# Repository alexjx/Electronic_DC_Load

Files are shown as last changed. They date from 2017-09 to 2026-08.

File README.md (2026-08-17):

# Electronic Controlled DC Dummy Load

An Arduino-compatible electronic load built around an ATmega328P. It draws a
controlled current from a DC source and displays the measured current, voltage,
power, temperature, and accumulated capacity.

> [!WARNING]
> This is an experimental high-power project, not a certified test instrument.
> The 15 A and 200 W values are firmware ceilings, not proven continuous hardware
> ratings. Safe operation depends on the input voltage, IRFP250N safe operating
> area, heatsink, airflow, shunt and PCB heating, wiring, connectors, calibration,
> and an external fuse. Begin with a current-limited supply at low power and do not
> leave the load unattended. The refactored firmware has not yet been validated on
> the physical hardware.

## Hardware overview

The load uses a power MOSFET as a variable resistance. A precision shunt measures
the resulting current, while the firmware adjusts a DAC until measured current
matches the requested value.

```text
Source under test -> J1 -> IRFP250N -> 5 mOhm shunt -> ground
                         ^                   |
                         |                   +-> INA213 -> AD7190 ADC
ATmega328P -> AD5541 DAC -> AD8629 gate-control amplifier
```

| Part | Purpose |
| --- | --- |
| ATmega328P-AU, 16 MHz | Runs the user interface, safety checks, and current controller |
| AD7190 | Measures load voltage and shunt current |
| AD5541 | Produces the analog current command |
| AD8629 | Buffers voltage sensing and drives the MOSFET control loop |
| INA213 and 5 mOhm / 4 W shunt | Measures load current |
| IRFP250N | Dissipates the power drawn from the source |
| LM35 | Measures heatsink temperature |
| 16x2 LCD and PCF8574 | Displays settings and measurements over I2C |
| REF5050 | Provides the 5 V ADC, DAC, and analog reference |

### Connections

| Connector | Function | Notes |
| --- | --- | --- |
| J1 | DC source under test | Schematic pad 2 is load positive; pad 1 is return/ground. Confirm this against the assembled PCB before applying power. |
| J2 | Control-power input | Feeds the MP1584 supply stage. The repository does not document a safe input-voltage range or jack polarity; verify the assembled board before use. |
| J3 | AVR ISP | Programming connector for the ATmega328P |
| J4 | Cooling fan | Nominal 12 V fan output controlled by the firmware |

The complete Eagle design is in [`schematic/`](schematic/). The design files
label the input-divider resistor as 9.9 kOhm, while the purchase record says the
fitted part is 9.09 kOhm. The firmware follows the purchase record; confirm the
assembled value and verify readings against calibrated meters before power testing.

## Controls and display

The top LCD row shows the current setpoint, cutoff voltage, and operating status.
A blank status means idle; `*` means the load is running. The LCD cursor identifies
the digit changed by the rotary encoder.

| Control | Action |
| --- | --- |
| Rotate encoder | Change the selected current or cutoff-voltage digit |
| S1 / D4 | Move the selected digit left |
| S4 / D6 | Move the selected digit right |
| S3 / D3 | Show the previous measurement page |
| S2 / D5 | Show the next measurement page |
| Hold encoder switch | Start loading after the controller has been idle for at least 3 seconds |
| Click encoder while running | Stop loading immediately |
| Click encoder on a cleared fault | Acknowledge the fault and return to idle |

The four bottom-row pages show:

1. Measured current and voltage.
2. Calculated power and heatsink temperature.
3. Session capacity in mAh.
4. Session energy in Wh.

The mAh and Wh counters reset whenever a new load session starts. The setpoints are
saved when a session starts or stops.

## Usage guide

1. With all power disconnected, inspect the board, fit an adequate heatsink and
   fan, and add a suitable external fuse to the source-under-test connection.
2. Confirm J1 polarity and the required J2 voltage and polarity from the actual
   assembled board. Connect the fan to J4, then apply control power to J2.
3. Check that the display starts normally and that no fault is reported. Verify the
   voltage, current, and temperature readings before enabling the power stage.
4. Use S1/S4 to select a digit and rotate the encoder to set the desired current and
   low-voltage cutoff. Start with a small current.
5. Turn the current-limited source off, connect it to J1 with the verified polarity,
   and then turn the source on.
6. After the controller has been idle for at least 3 seconds, hold the encoder switch
   until loading starts. Confirm that `*` appears and watch current, power, and
   temperature while testing.
7. Click the encoder to stop. Confirm that `*` disappears before disconnecting the
   source.

The firmware limits the setpoint to 15.000 A, reduces the current request above a
calculated 200 W, trips overcurrent at 16.5 A, and trips overtemperature at 95 degC.
These protections supplement rather than replace correctly rated hardware and an
external fuse.

### Faults

Any firmware fault commands the DAC to zero and latches the load off.

| Display | Meaning | Before acknowledging |
| --- | --- | --- |
| `FAULT ADC` | ADC did not initialize or respond in time | Check ADC power, SPI wiring, and ready signal |
| `FAULT TEMP SNS` | Temperature reading is outside the plausible sensor range | Check the LM35 and its wiring |
| `FAULT OVERCUR` | Measured current exceeded 16.5 A | Remove the cause of excess current |
| `FAULT UNDERVOLT` | Source voltage fell below the configured cutoff | Recharge, replace, or disconnect the source |
| `FAULT OVERTEMP` | Temperature exceeded 95 degC | Keep cooling active and wait for the load to cool |

After correcting the cause, click the encoder when the display says
`Click to ack`. Acknowledgement only returns the controller to idle; it does not
restart the load. A condition that is still unsafe will fault again or refuse to
clear.

## Firmware build and tests

Initialize the pinned libraries, then build the Arduino Uno firmware:

```sh
git submodule update --init --recursive
make -C code clean
make -C code
```

Run the hardware-independent safety and driver tests with:

```sh
make -C code/tests clean
make -C code/tests
```

See [`code/BUILDING.md`](code/BUILDING.md) for the tested Ubuntu/WSL environment,
tool versions, generated files, and current flashing limitations.

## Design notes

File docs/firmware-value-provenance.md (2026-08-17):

# Firmware Value Provenance

This document records where the firmware's electrical conversion constants and
protection limits came from. It separates values confirmed by the repository's
schematic and PCB from engineering policy values that still require physical
validation.

## Source priority

Values are resolved in this order:

1. The component actually fitted to the assembled board.
2. The [schematic](../schematic/Electronic%20DC%20Load.sch) and
   [PCB](../schematic/Electronic%20DC%20Load.brd).
3. Manufacturer datasheets for the confirmed fitted component.
4. Existing firmware behavior.
5. Conservative firmware policy where the hardware does not define a value.

The repository labels current-sense amplifier U3 as an INA210. The assembled
board is reported to use an **INA213**, so the firmware intentionally uses the
INA213 nominal gain of 50 V/V. This override should be confirmed from the
physical package marking or purchase record.

The schematic and PCB label input-divider resistor R5 as 9.9 kOhm. The purchase
record instead identifies the fitted value as **9.09 kOhm**. The firmware uses
the fitted value, giving a 10.09:1 divider with R11. A resistance measurement on
an unpowered board should confirm it when practical.

## Confirmed transfer values

| Quantity | Repository evidence | Firmware value | Confidence |
| --- | --- | ---: | --- |
| Analog reference | U1, REF5050 | 5.0 V | High |
| Current shunt | R1, `.005` | 5 mOhm | High |
| Current-sense gain | Fitted U3 reported as INA213 | 50 V/V | Medium until physically confirmed |
| Input-voltage divider | Purchase record: R5 = 9.09 kOhm; R11 = 1 kOhm | 10.09:1 | Medium until physically confirmed |
| DAC divider | R12 = 39 kOhm, R8 = 10 kOhm | 10/49 | High |
| ADC | U2, AD7190BRUZ | AD7190 | High |
| DAC | U6, AD5541ARZ | AD5541 | High |

The schematic and PCB agree on the reference, shunt, and DAC-divider values.
They disagree with the purchase record for input-divider R5. Net tracing
confirms that R5/R11 feed the voltage measurement path and R12/R8 feed the
AD8629 current-control loop.

The single source of truth for these nominal values is
[`code/control.h`](../code/control.h). The ADC adapter uses the same functions
for its uncalibrated safety readings, avoiding a second set of constants.

## Current measurement

For a 5 mOhm shunt and INA213 gain of 50 V/V:

```text
amplifier_output = load_current * 0.005 * 50
                 = load_current * 0.25

load_current = amplifier_output / 0.25
```

At 15 A, the nominal amplifier output is 3.75 V.

This equation is used for absolute current and power protection without applying
the historical calibration coefficients.

## Input-voltage measurement

The fitted R5 and R11 values form a 9.09 kOhm / 1 kOhm divider:

```text
divider_ratio = (9.09k + 1k) / 1k
              = 10.09

input_voltage = ADC_input * 10.09
```

At a 50 V input, the nominal ADC input is approximately 4.955 V. The theoretical
5 V measurement full scale corresponds to only 50.45 V at the load input. The
present 50 V firmware trip therefore has less than 1% nominal input-voltage
headroom. It should not be increased, and lowering it requires deciding the
intended maximum operating voltage. In either case, this calculation is **not**
proof that the complete load is safe to dissipate power near 50 V.

## DAC current command

The AD5541 output is divided by R12 and R8 before reaching the AD8629 current
servo. The servo compares that target with the voltage across the 5 mOhm shunt:

```text
DAC_voltage = DAC_code / 65536 * 5.0

target_shunt_voltage = DAC_voltage * 10k / (39k + 10k)

target_current = target_shunt_voltage / 0.005
```

The ideal DAC code for 15 A is:

```text
15 * 0.005 * (39k + 10k) / 10k * 65536 / 5
= 4816.896 codes
```

The current firmware rounds this to a 4,817-code hard ceiling, corresponding to
approximately 15.0003 A nominally. A strict mathematical safety floor would be
4,816 codes, corresponding to approximately 14.9972 A. Component tolerances are
much larger than this one-code difference, but flooring is the cleaner policy
when the limit must never exceed nominal 15 A.

## Calibration boundary

The existing ADC calibration coefficients have no documented provenance:

| AD7190 gain | Scale | Offset |
| --- | ---: | ---: |
| 1 | 1.00080 | 4.0 mV |
| 8 | 1.00243 | -0.60 mV |

They remain available for displayed measurements and session accounting. They
do not change the nominal current, voltage, power, or DAC safety ceilings.
Accurate display and energy results require these coefficients to be confirmed
with traceable bench measurements.

## Engineering policy values

The following values are not directly established by resistor ratios or a
validated system-level hardware rating:

| Policy | Current value | Basis and limitation | Confidence as a safe physical limit |
| --- | ---: | --- | --- |
| User current ceiling | 15 A | Historical firmware setting and nominal DAC model | Medium |
| Overcurrent trip | 16.5 A | 10% above the command ceiling; backup protection | Medium |
| Input-voltage trip | 50 V | Only 0.45 V nominal source-side ADC headroom with the fitted divider | Low |
| Measured-power trip | 200 W | Retained historical firmware value | Low |
| Continuous command limit | 180 W | 10% margin below the historical value | Low |
| Thermal derating start | 80 C | Conservative firmware policy | Low |
| Thermal trip | 95 C | Historical firmware value | Low |
| Upward current slew | 5 A/s | Firmware transient-limiting policy | Medium |
| No-source threshold | 0.1 V | Noise/compliance guard | Medium |
| Cutoff qualification | 500 ms, 0.1 V hysteresis | Noise-rejection policy | Medium |
| AD7190 conversion timeout | 100 ms | Expected conversion time plus margin | Medium |
| I2C transaction timeout | 1 ms | Expected 100 kHz bus transaction plus margin | Medium |

In particular, 180 W or 200 W must not be interpreted as a validated continuous
rating. The safe load envelope depends on the IRFP250N DC safe-operating-area
curve, drain voltage, heatsink thermal resistance, airflow, ambient temperature,
sensor placement, gate-loop stability, wiring, and protection response time.

## Required physical verification

Before relying on the limits for real power testing:

1. Confirm that U3 on the assembled board is an INA213.
2. Confirm the fitted shunt and divider values, especially the R5 discrepancy,
   including tolerances.
3. Measure the REF5050 voltage and the current-to-DAC transfer at low power.
4. Verify ADC current and voltage readings against traceable instruments.
5. Establish a conservative voltage/current/time envelope from the fitted
   IRFP250N datasheet and actual cooling system.
6. Measure startup, current-step, source-disconnect, fault, and stop transients
   with an oscilloscope.
7. Validate heatsink, fan, and LM35 behavior at controlled increasing power.
8. Confirm that the ADC and I2C timeout margins are reliable on the assembled
   hardware.

Until these checks are complete, the firmware limits should be treated as
defensive bounds derived from the available design information, not as a
certified operating envelope.

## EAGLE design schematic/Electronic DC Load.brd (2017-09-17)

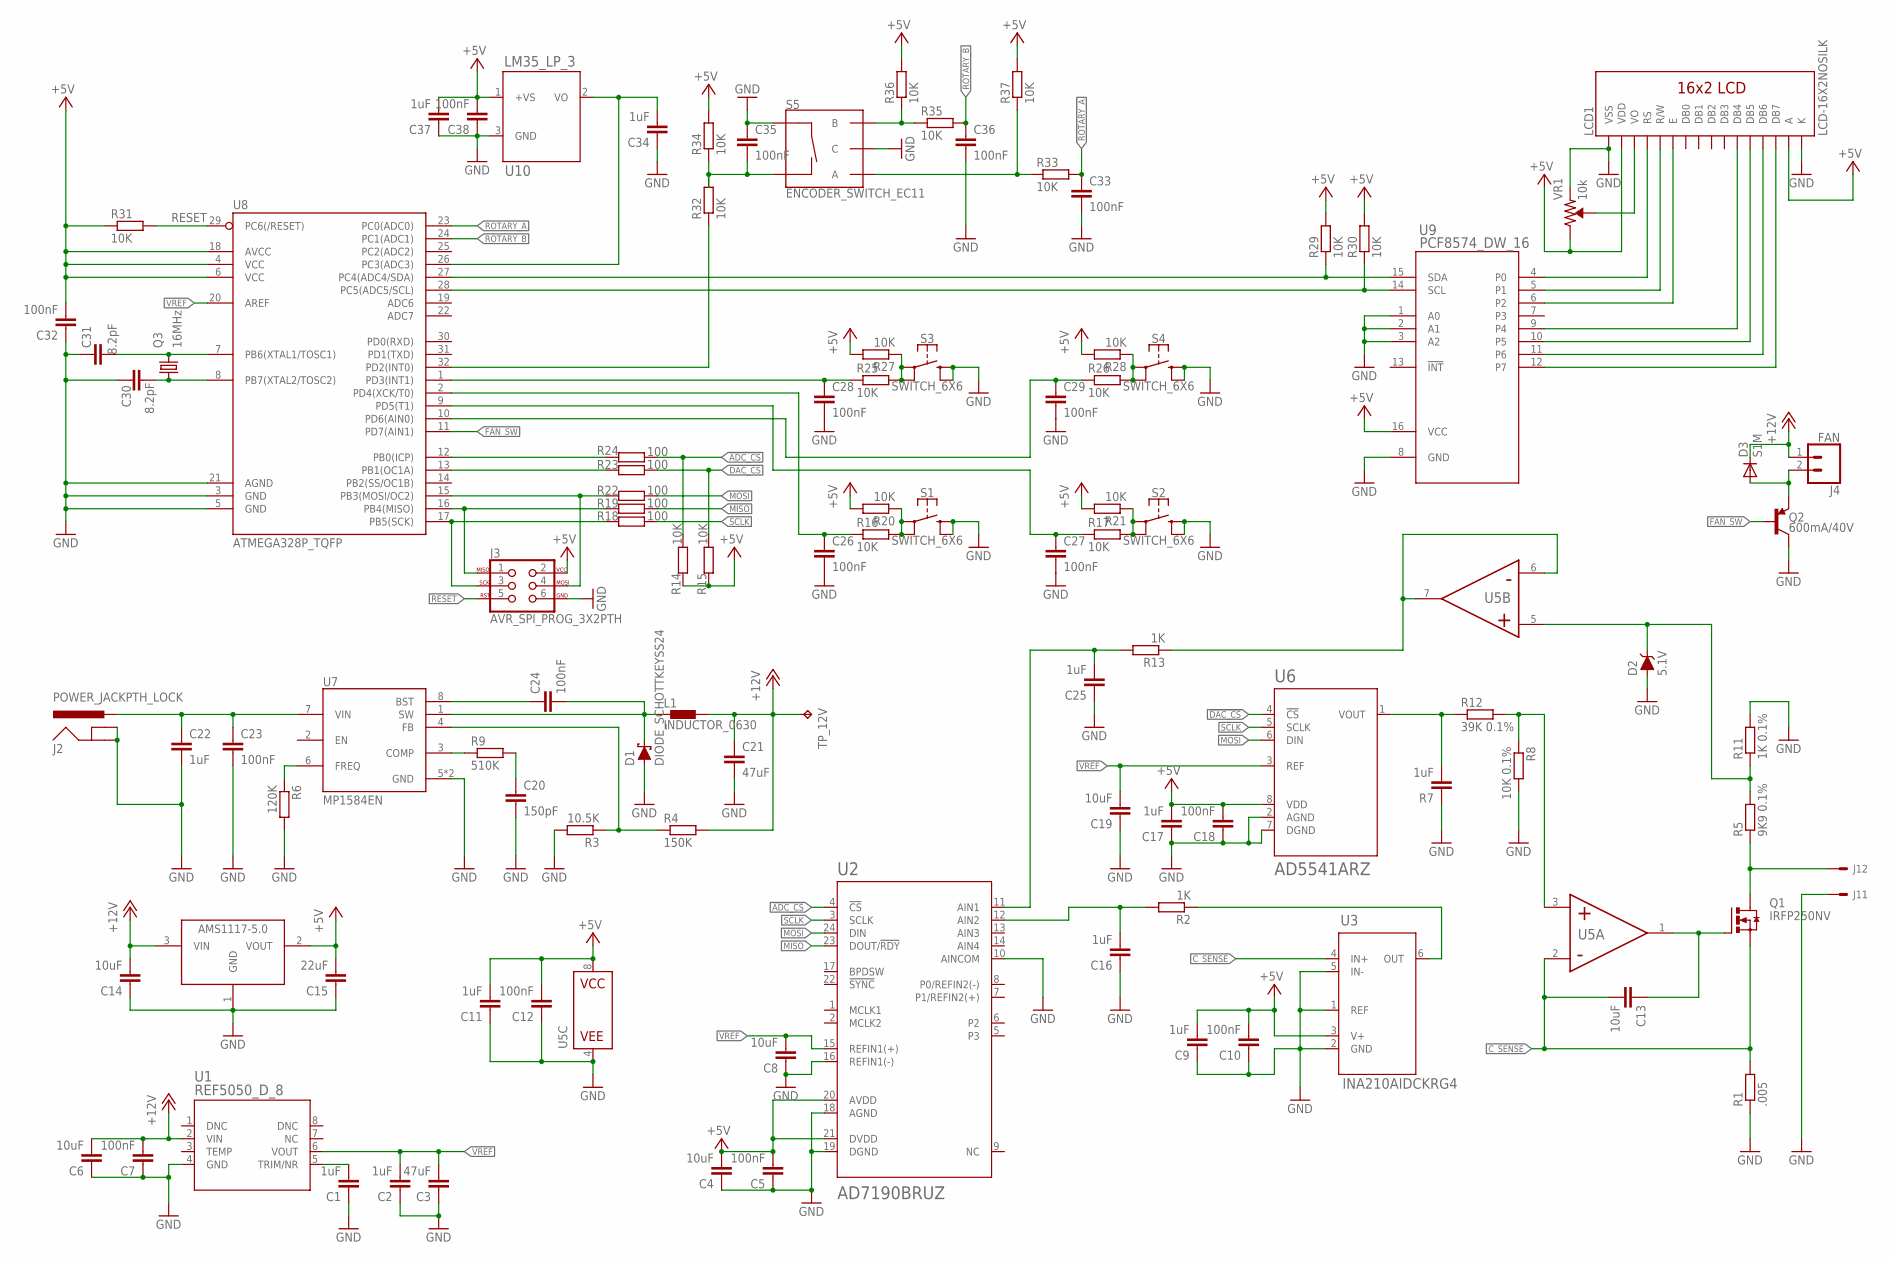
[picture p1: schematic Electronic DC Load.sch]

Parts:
C1, C2, C9, C11, C16, C17, C22, C25, C34, C37: 1uF; C0805
C3, C21: 47uF; C1206
C4, C6, C8, C13, C14, C19: 10uF; C1206
C5, C7, C10, C12, C18, C23, C24, C38: 100nF; C0805
C15: 22uF; C1206
C20: 150pF; C0402
C26, C27, C28, C29, C32, C33, C35, C36: 100nF; C0603
C30, C31: 8.2pF; C0603
D1: DIODE_SCHOTTKEYSS24; SMA-DIODE
D2: 5.1V; LL-34
D3: S1M; SMA
J1: KF762-2
J2: POWER_JACKPTH_LOCK; POWER_JACK_PTH_LOCK
J3: AVR_SPI_PROG_3X2PTH; 2X3
J4: FAN; 1X02_LOCK_LONGPADS
L1: INDUCTOR_0630
LCD1: LCD-16X2NOSILK; LCD-16X2_NOSILK
Q1: IRFP250NV; TO247BV
Q2: 600mA/40V; SOT23-3
Q3: 16MHz; 3.2X2.5_KX-7
R1: .005; 2728
R2, R13: 1K; R0805
R3: 10.5K; R0603
R4: 150K; R0603
R5: 9K9 0.1%; M0805
R6: 120K; R0603
R7: 1uF; C0805
R8: 10K 0.1%; R0805
R9: 510K; R0603
R11: 1K 0.1%; M0805
R12: 39K 0.1%; R0805
R14, R15: 10K; M0805
R16, R17, R20, R21, R25, R26, R27, R28, R29, R30, R31, R32, R33, R34, R35, R36, R37: 10K; R0603
R18, R19, R22, R23, R24: 100; M0805
S1, S2, S3, S4: SWITCH_6X6; SWITCH_SMD_6MM
S5: ENCODER_SWITCH_EC11; ROTARY_ENCODER_EC11
TP_12V: TPB1,27; B1,27
U1: REF5050_D_8; D8
U2: AD7190BRUZ; RU_24
U3: INA210AIDCKRG4; DCK0006A_N
U4: AMS1117-5.0; SOT223
U5: AD8629ARZ; R_8
U6: AD5541ARZ; R_8
U7: MP1584EN; SOIC9P127_490X600X170L84X42T330X241N
U8: ATMEGA328P_TQFP; TQFP32-08
U9: PCF8574_DW_16; DW16
U10: LM35_LP_3; Z03A
VR1: 10k; TRIMPOT-SMD-TC33X

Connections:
!ADC_CS: R14.2, R24.2, U2.4 (!CS)
!DAC_CS: R15.2, R23.2, U6.4 (!CS)
+5V: C4.2, C5.2, C9.2, C10.2, C11.2, C12.2, C15.2, C17.2, C18.2, C32.2, C37.2, C38.2, J3.2, LCD1.2 (VDD), LCD1.15 (A), R14.1, R15.1, R20.2, R21.2, R27.2, R28.2, R29.2, R30.2, R31.1, R34.2, R36.2, R37.2, U2.20 (AVDD), U2.21 (DVDD), U3.3 (V+), U4.2 (VOUT), U5.8 (VCC), U6.8 (VDD), U8.4 (VCC), U8.6 (VCC), U8.18 (AVCC), U9.16 (VCC), U10.1 (+VS), VR1.1 (CW)
+12V: C6.2, C7.2, C14.2, C21.1, D3.C, J4.1, L1.P$2 (2), R4.2, TP_12V.TP, U1.2 (VIN), U4.3 (VIN)
C_SENSE: C13.2, Q1.S, R1.2, U3.4 (IN+), U5.2 (IN-)
FAN_SW: Q2.1 (B), U8.11 (PD7(AIN1))
GND: C1.1, C2.1, C3.1, C4.1, C5.1, C6.1, C7.1, C8.1, C9.1, C10.1, C11.1, C12.1, C14.1, C15.1, C16.1, C17.1, C18.1, C19.1, C20.2, C21.2, C22.2, C23.2, C25.1, C26.2, C27.2, C28.2, C29.2, C30.1, C31.1, C32.1, C33.2, C34.1, C35.1, C36.2, C37.1, C38.1, D1.A, D2.A, J1.1, J2.GND, J2.GNDBREAK, J3.6, LCD1.1 (VSS), LCD1.16 (K), Q2.3 (C), R1.1, R3.2, R6.2, R7.1, R8.2, R11.2, S1.B1 (3), S1.B2 (4), S2.B1 (3), S2.B2 (4), S3.B1 (3), S3.B2 (4), S4.B1 (3), S4.B2 (4), S5.C, S5.D (SW+), U1.4 (GND), U2.10 (AINCOM), U2.16 (REFIN1(-)), U2.18 (AGND), U2.19 (DGND), U3.1 (REF), U3.2 (GND), U3.5 (IN-), U4.1 (GND), U5.4 (VEE), U6.2 (AGND), U6.7 (DGND), U7.5 (GND), U7.9 (GND), U8.3 (GND), U8.5 (GND), U8.21 (AGND), U9.1 (A0), U9.2 (A1), U9.3 (A2), U9.8 (GND), U10.3 (GND), VR1.3 (CCW)
MISO: R19.2, U2.23 (DOUT/!RDY)
MOSI: R22.2, U2.24 (DIN), U6.6 (DIN)
unnamed: R29.1, U8.27 (PC4(ADC4/SDA)), U9.15 (SDA)
unnamed: R30.1, U8.28 (PC5(ADC5/SCL)), U9.14 (SCL)
unnamed: LCD1.11 (DB4), U9.9 (P4)
unnamed: LCD1.12 (DB5), U9.10 (P5)
unnamed: LCD1.13 (DB6), U9.11 (P6)
unnamed: LCD1.14 (DB7), U9.12 (P7)
unnamed: LCD1.4 (RS), U9.4 (P0)
unnamed: LCD1.5 (R/W), U9.5 (P1)
unnamed: LCD1.6 (E), U9.6 (P2)
unnamed: C1.2, U1.5 (TRIM/NR)
unnamed: C31.2, Q3.3 (2), U8.7 (PB6(XTAL1/TOSC1))
unnamed: C30.2, Q3.1, U8.8 (PB7(XTAL2/TOSC2))
unnamed: LCD1.3 (VO), VR1.2 (WIPER)
unnamed: J1.2, Q1.D, R5.1
unnamed: C34.2, U8.26 (PC3(ADC3)), U10.2 (VO)
unnamed: C25.2, R13.2, U2.11 (AIN1)
unnamed: R6.1, U7.6 (FREQ)
unnamed: R2.1, U3.6 (OUT)
unnamed: C24.1, U7.8 (BST)
unnamed: C22.1, C23.1, J2.PWR, U7.7 (VIN)
unnamed: C24.2, D1.C, L1.P$1 (1), U7.1 (SW)
unnamed: R3.1, R4.1, U7.4 (FB)
unnamed: R9.1, U7.3 (COMP)
unnamed: C16.2, R2.2, U2.12 (AIN2)
unnamed: C20.1, R9.2
unnamed: R7.2, R12.1, U6.1 (VOUT)
unnamed: R13.1, U5.6 (IN-), U5.7 (OUT)
unnamed: D3.A, J4.2, Q2.2 (E)
unnamed: R35.1, R36.1, S5.B
unnamed: J3.3, R18.1, U8.17 (PB5(SCK))
unnamed: J3.1, R19.1, U8.16 (PB4(MISO))
unnamed: J3.4, R22.1, U8.15 (PB3(MOSI/OC2))
unnamed: R23.1, U8.13 (PB1(OC1A))
unnamed: R24.1, U8.12 (PB0(ICP))
unnamed: C13.1, Q1.G, U5.1 (OUT)
unnamed: D2.C, R5.2, R11.1, U5.5 (IN+)
unnamed: R33.1, R37.1, S5.A
unnamed: R8.1, R12.2, U5.3 (IN+)
unnamed: R16.2, R20.1, S1.A1 (1), S1.A2 (2)
unnamed: R25.2, R27.1, S3.A1 (1), S3.A2 (2)
unnamed: C35.2, R32.2, R34.1, S5.E (SW-)
unnamed: C26.1, R16.1, U8.2 (PD4(XCK/T0))
unnamed: R32.1, U8.32 (PD2(INT0))
unnamed: C28.1, R25.1, U8.1 (PD3(INT1))
unnamed: R26.2, R28.1, S4.A1 (1), S4.A2 (2)
unnamed: R17.2, R21.1, S2.A1 (1), S2.A2 (2)
unnamed: C27.1, R17.1, U8.9 (PD5(T1))
unnamed: C29.1, R26.1, U8.10 (PD6(AIN0))
RESET: J3.5, R31.2, U8.29 (PC6(/RESET))
ROTARY_A: C33.1, R33.2, U8.23 (PC0(ADC0))
ROTARY_B: C36.1, R35.2, U8.24 (PC1(ADC1))
SCLK: R18.2, U2.3 (SCLK), U6.5 (SCLK)
VREF: C2.2, C3.2, C8.2, C19.2, U1.6 (VOUT), U2.15 (REFIN1(+)), U6.3 (REF), U8.20 (AREF)

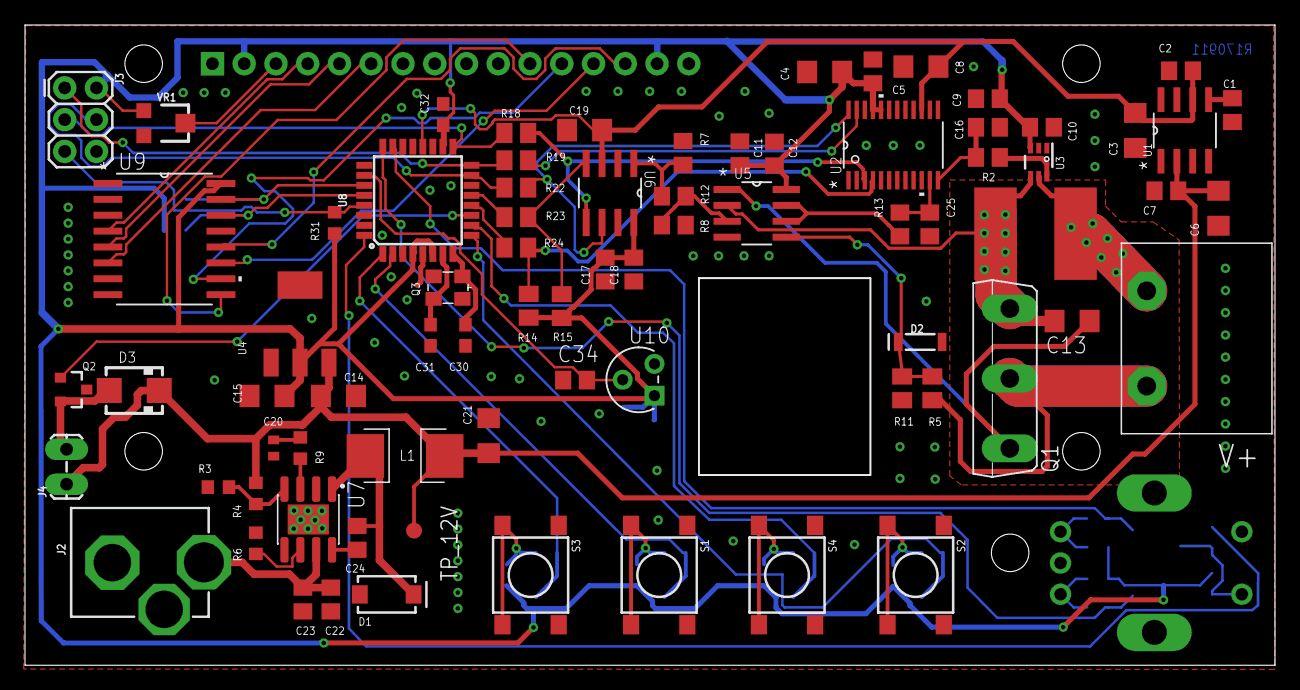
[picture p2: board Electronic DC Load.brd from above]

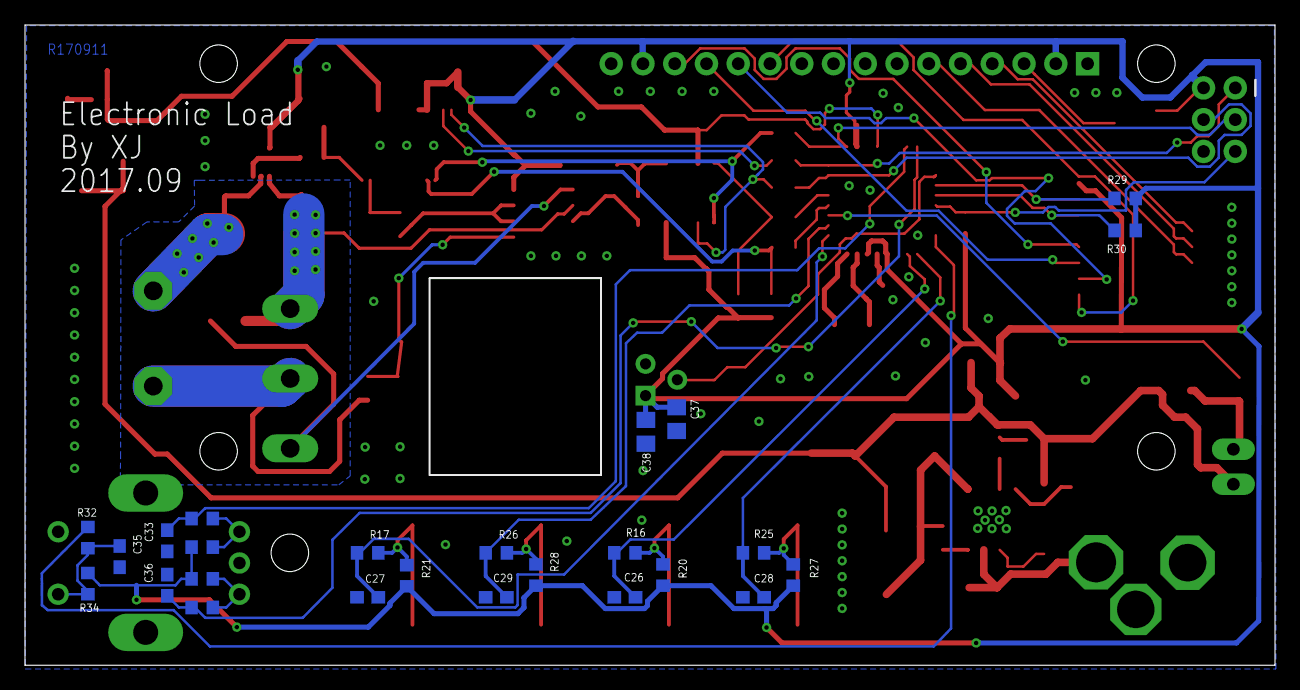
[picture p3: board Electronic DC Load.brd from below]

Board: 2 copper layers, 100.0 x 51.2 mm, 103 parts (25 on the bottom side), 62 nets.

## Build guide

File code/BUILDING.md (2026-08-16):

# Building the firmware in WSL

The firmware targets an Arduino Uno-compatible ATmega328P running at 16 MHz.

## One-time setup

On Ubuntu 22.04 under WSL:

```sh
sudo apt-get update
sudo apt-get install -y arduino-core-avr arduino-mk gcc-avr avr-libc avrdude make g++
git submodule update --init --recursive
```

The repository pins the external Arduino libraries through Git submodules. The
Ubuntu packages provide the AVR compiler, Arduino AVR core, and Arduino-Makefile.

Versions used to reproduce the baseline build:

- Arduino AVR core: `1.8.4+dfsg1-1`
- Arduino-Makefile: `1.5.2-2.1`
- avr-gcc/avr-g++: `5.4.0`
- avr-libc: `2.0.0`
- GNU Make: `4.3`

## Build

From the repository root:

```sh
make -C code clean
make -C code
```

Build artifacts are written under `code/bin/` and ignored by Git. The `.hex`
file is the image used for flashing.

## Host safety tests

Run the hardware-independent controller and driver tests with:

```sh
make -C code/tests clean
make -C code/tests
```

The tests use strict compiler warnings plus AddressSanitizer and
UndefinedBehaviorSanitizer. Test binaries are written to
`/tmp/electronic_dc_load_tests`, not the repository.

The Makefile defaults to the Ubuntu package location, `/usr/share/arduino`.
`ARDMK_DIR` and `ARDUINO_DIR` can still be overridden on the command line for a
different installation.

## WSL hardware note

Compiling does not require USB access. Uploading from WSL additionally requires
the Arduino's USB serial device to be attached to WSL and may require adjusting
`MONITOR_PORT`; flashing has not yet been verified on physical hardware.

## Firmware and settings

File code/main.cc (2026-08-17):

#include <Arduino.h>
#include <Wire.h>
#include <SPI.h>
#include <TimerOne.h>
#include <LiquidCrystal_I2C.h>
#include <ClickEncoder.h>
#include <EEPROM.h>

#include "ad5541.h"
#include "adc.h"
#include "button.h"
#include "fan.h"
#include "setter.h"
#include "lm35.h"
#include "control.h"


// Hardware Configuration
#define LCD_IIC_ADDRESS      0x20
#define LCD_IIC_COLS         16
#define LCD_IIC_ROWS         2

#define ENCODER_PIN_1        A0
#define ENCODER_PIN_2        A1
#define ENCODER_SW_PIN       2
#define ENCODER_UPDATE_RATE  4


#define ADC_CS_PIN           8
#define DAC_CS_PIN           9

#define BUTTON_1_PIN         3
#define BUTTON_2_PIN         4
#define BUTTON_3_PIN         6
#define BUTTON_4_PIN         5

#define FAN_SW_PIN           7
#define LM35_PIN             A3

#define MAX_BUTTON           4

#define ADC_CURRENT_CHN      AD7190_CH_AIN2P_AINCOM
#define ADC_VOLTAGE_CHN      AD7190_CH_AIN1P_AINCOM

#define EEPROM_VERSION_ADDR  0x00
#define EEPROM_VERSION       0x0a

#define EEPROM_CURRENT_ADDR  0x10
#define EEPROM_VOLTAGE_ADDR  0x20


// Constants
const double VREF_VOLTAGE = 5000.0;  // mV

const double MAX_WATTAGE = 200.0;
const double CONTINUOUS_WATTAGE = 180.0;
const double MAX_INPUT_VOLTAGE = 50.0;
const double MIN_SOURCE_VOLTAGE = 0.1;

constexpr int32_t MAX_CURRENT_MILLIAMPS = 15000;
constexpr double MAX_CURRENT = MAX_CURRENT_MILLIAMPS / 1000.0;

const double MAX_TEMPERATURE = 95.0;
const double THERMAL_DERATE_START = 80.0;

const int MAX_PAGE = 4;
const uint32_t DISPLAY_UPDATE_INTERVAL_MS = 200UL;
const uint32_t WIRE_TIMEOUT_US = 1000UL;


///////////////////////
// Devices
///////////////////////

// DAC
AD5541 ad5541(DAC_CS_PIN);


// ADC
ADConverter adc(ADC_CS_PIN,
                ADC_VOLTAGE_CHN,
                ADC_CURRENT_CHN,
                VREF_VOLTAGE);


// LCD
LiquidCrystal_I2C lcd(LCD_IIC_ADDRESS,
                      LCD_IIC_COLS,
                      LCD_IIC_ROWS);


// encoder
ClickEncoder encoder(ENCODER_PIN_1,
                     ENCODER_PIN_2,
                     ENCODER_SW_PIN,
                     ENCODER_UPDATE_RATE);


// Buttons
Button buttons[MAX_BUTTON] {
    BUTTON_1_PIN,
    BUTTON_2_PIN,
    BUTTON_3_PIN,
    BUTTON_4_PIN,
};


// FAN
FanController fan(FAN_SW_PIN);


// temperature sensor
LM35 lm35(LM35_PIN, VREF_VOLTAGE);


// Setter (max 15000mA)
Setter<MAX_CURRENT_MILLIAMPS> current_set_point;
// Cut off voltage set
Setter<99999l> voltage_set_point;

// 0 - 4 current 5 - 9 cut off voltage
int8_t setter_position = 4;
const int MAX_SET_POSITION = 10;


//////////////////////////////
// Operations
//////////////////////////////

// Global Data
struct {
    control::ControllerState controller;
    control::MeasurementSnapshot measurement;

    double mah;
    double watt_h;
    uint32_t update_last;
    bool adc_initialized;
    bool display_available;
    bool stop_armed;
    bool start_press_active;
    uint32_t start_pressed_ms;
    uint32_t output_last;
    uint32_t display_last;
    control::UndervoltageQualification undervoltage;

    // page
    int page;

} g_cb {
    control::ControllerState(),
    control::MeasurementSnapshot(),
    0.0, 0.0, 0, false, true, false, false, 0, 0, 0,
    control::UndervoltageQualification(), 0
};


void SetLoadOutput(uint16_t code)
{
    if (code > control::kTheoreticalDacHardCapCode) {
        code = control::kTheoreticalDacHardCapCode;
    }
    ad5541.setValue(code);
}



// timer service
void timer_one_isr()
{
    encoder.service();
}


void UpdateButtons()
{
    for (int i = MAX_BUTTON; i > 0; i--) {
        buttons[i - 1].update();
    }
}


bool HandleImmediateStop();


bool UpdateCurrentVoltage()
{
    if (!g_cb.adc_initialized) {
        adc.resetCurrent();
        g_cb.measurement.current = 0.0;
        g_cb.measurement.voltage = 0.0;
        g_cb.measurement.safety_current = 0.0;
        g_cb.measurement.safety_voltage = 0.0;
        g_cb.measurement.current_valid = false;
        g_cb.measurement.voltage_valid = false;
        g_cb.measurement.safety_current_valid = false;
        g_cb.measurement.safety_voltage_valid = false;
        return true;
    }

    const bool current_valid = adc.updateCurrent();
    if (!current_valid) {
        g_cb.measurement.current = adc.readCurrent();
        g_cb.measurement.voltage = adc.readVoltage();
        g_cb.measurement.current_valid = false;
        g_cb.measurement.voltage_valid = false;
        g_cb.measurement.safety_current_valid = false;
        g_cb.measurement.safety_voltage_valid = false;
        return true;
    }

    // Do not make an intentional stop wait for the second ADC conversion.
    if (HandleImmediateStop()) {
        return false;
    }

    const bool voltage_valid = adc.updateVoltage();

    g_cb.measurement.current = adc.readCurrent();
    g_cb.measurement.voltage = adc.readVoltage();
    g_cb.measurement.safety_current = adc.readSafetyCurrent();
    g_cb.measurement.safety_voltage = adc.readSafetyVoltage();
    g_cb.measurement.current_valid = current_valid;
    g_cb.measurement.voltage_valid = voltage_valid;
    g_cb.measurement.safety_current_valid = current_valid;
    g_cb.measurement.safety_voltage_valid = voltage_valid;
    return true;
}


void UpdateTemperature()
{
    lm35.update();
}


bool UpdateSensors()
{
    // update inputs
    UpdateButtons();

    // sensors
    const bool control_processing_allowed = UpdateCurrentVoltage();
    UpdateTemperature();

    g_cb.measurement.temperature = lm35.getTemperature();
    g_cb.measurement.temperature_valid = lm35.isValid();
    g_cb.measurement.timestamp_ms = millis();
    return control_processing_allowed;
}


/// Display a double with Fixed length
void DisplayFixedDouble(double value, int width, int prec)
{
    char line[20];
    dtostrf(value, width, prec, line);
    int len = strlen(line);
    if (len > width) {
        // if we have longger value, truncate it
        line[width] = '\0';
    } else {
        // if the first one is space then we have leading spaces
        if (line[0] == ' ') {
            for (char* p = strchr(line, ' '); p; p = strchr(line, ' ')) {
                *p = '0';
            }
        }
    }
    lcd.print(line);
}


bool UpdateDisplay()
{
    lcd.noCursor();
    if (Wire.getWireTimeoutFlag()) {
        return false;
    }

    if (g_cb.controller.state == control::OperationState::Fault) {
        lcd.setCursor(0, 0);
        switch (g_cb.controller.fault) {
            case control::FaultReason::AdcFailure:
                lcd.print(F("FAULT ADC       "));
                break;
            case control::FaultReason::TemperatureSensorFailure:
                lcd.print(F("FAULT TEMP SNS  "));
                break;
            case control::FaultReason::Overcurrent:
                lcd.print(F("FAULT OVERCUR   "));
                break;
            case control::FaultReason::Undervoltage:
                lcd.print(F("FAULT UNDERVOLT "));
                break;
            case control::FaultReason::Overtemperature:
                lcd.print(F("FAULT OVERTEMP  "));
                break;
            case control::FaultReason::Overvoltage:
                lcd.print(F("FAULT OVERVOLT  "));
                break;
            case control::FaultReason::Overpower:
                lcd.print(F("FAULT OVERPOWER "));
                break;
            case control::FaultReason::NoSource:
                lcd.print(F("FAULT NO SOURCE "));
                break;
            case control::FaultReason::DisplayFailure:
                lcd.print(F("FAULT DISPLAY   "));
                break;
            default:
                lcd.print(F("FAULT UNKNOWN   "));
                break;
        }
        lcd.setCursor(0, 1);
        if (g_cb.controller.fault == control::FaultReason::AdcFailure) {
            lcd.print(F("Click to retry  "));
        } else {
            lcd.print(F("Click to ack    "));
        }
        return !Wire.getWireTimeoutFlag();
    }

    if (g_cb.controller.state == control::OperationState::Completed) {
        lcd.setCursor(0, 0);
        lcd.print(F("DONE: CUTOFF    "));
        lcd.setCursor(0, 1);
        lcd.print(F("Click to finish "));
        return !Wire.getWireTimeoutFlag();
    }

    // Display
    // Line 1 - Current Set Point, temperature:
    //   aa.aaaA ttt.ttC X
    lcd.setCursor(0, 0);
    DisplayFixedDouble(current_set_point.as_double(), 6, 3);
    lcd.print("A ");
    DisplayFixedDouble(voltage_set_point.as_double(), 6, 3);
    lcd.print("V");

    // FIXME: print out status
    switch (g_cb.controller.state) {
        case control::OperationState::Idle:
            lcd.print(" ");
            break;
        case control::OperationState::Running:
            lcd.print("*");
            break;
        default:
            lcd.print("?");
    }
    if (Wire.getWireTimeoutFlag()) {
        return false;
    }

    // Line 2 - Current Sensing, Voltage Sensing:
    //   ss.ssssA vvv.vvvV
    lcd.setCursor(0, 1);

    if (g_cb.page == 0) {
        DisplayFixedDouble(g_cb.measurement.current, 6, 3);
        lcd.print("A ");
        DisplayFixedDouble(g_cb.measurement.voltage, 6, 3);
        lcd.print("V ");
    } else if (g_cb.page == 1) {
        double wattage = g_cb.measurement.voltage * g_cb.measurement.current;
        DisplayFixedDouble(wattage, 8, 4);
        lcd.print("W ");
        DisplayFixedDouble(g_cb.measurement.temperature, 5, 2);
        lcd.print("C");
    } else if (g_cb.page == 2) {
        DisplayFixedDouble(g_cb.mah, 8, 2);
        lcd.print("mAh     ");
    } else if (g_cb.page == 3) {
        DisplayFixedDouble(g_cb.watt_h, 8, 2);
        lcd.print("Wh      ");
    }

    // positiont the cursor for showing
    // current 01.345A 89.123V
    uint8_t bit = setter_position;
    if (setter_position >= 2) {
        bit++;
    }
    if (setter_position > 4) {
        bit += 2;
    }
    if (setter_position >= 7) {
        bit++;
    }
    lcd.setCursor(bit, 0);
    lcd.cursor();
    return !Wire.getWireTimeoutFlag();
}

void SaveSetPointToEEPROM()
{
    current_set_point.save_to_eeprom(EEPROM_CURRENT_ADDR);
    voltage_set_point.save_to_eeprom(EEPROM_VOLTAGE_ADDR);
}


void UpdateCursorPosition()
{
    if (setter_position < 5) {
        current_set_point.set_position(setter_position);
    } else {
        voltage_set_point.set_position(setter_position - 5);
    }
}


void StopDischarge()
{
    SetLoadOutput(0);
    control::stop(g_cb.controller, millis());
    control::resetUndervoltageQualification(g_cb.undervoltage);
    SaveSetPointToEEPROM();
}


bool HandleImmediateStop()
{
    if (g_cb.controller.state != control::OperationState::Running) {
        return false;
    }

    const bool encoder_pressed = digitalRead(ENCODER_SW_PIN) == LOW;
    if (!encoder_pressed) {
        g_cb.stop_armed = true;
        return false;
    }
    if (!g_cb.stop_armed) {
        return false;
    }

    StopDischarge();
    return true;
}


void LatchFault(control::FaultReason reason, uint32_t now)
{
    SetLoadOutput(0);
    control::latchFault(g_cb.controller, reason, now);
}


void CompleteDischarge(uint32_t now)
{
    SetLoadOutput(0);
    control::complete(g_cb.controller, now);
    SaveSetPointToEEPROM();
}


bool StartDischarge(uint32_t held_since_ms)
{
    uint32_t now = millis();
    if (!control::tryStart(g_cb.controller,
                           now,
                           held_since_ms,
                           true)) {
        return false;
    }

    SetLoadOutput(0);
    g_cb.mah = 0;
    g_cb.watt_h = 0;
    g_cb.update_last = now;
    g_cb.output_last = now;
    g_cb.stop_armed = false;
    g_cb.start_press_active = false;
    control::resetUndervoltageQualification(g_cb.undervoltage);
    SaveSetPointToEEPROM();
    return true;
}


bool InitializeAdc()
{
    adc.begin();
    if (!adc.detectDevice() || !adc.init()) {
        return false;
    }

    // Calibration improves operating/display accuracy only. Absolute safety
    // readings use the separate nominal schematic path in ADConverter.
    adc.setCalibData(AD7190_CONF_GAIN_1, 1.00080, 4.0);
    adc.setCalibData(AD7190_CONF_GAIN_8, 1.00243, -0.60);
    return true;
}


void ProcessControl()
{
    // All control decisions in this pass use the same sensor sample.
    const uint32_t now = g_cb.measurement.timestamp_ms;
    const control::MeasurementSnapshot& measurement = g_cb.measurement;

    // A failed/unsafe reading is handled before any user input or DAC
    // processing.  This also keeps a newly latched fault from restarting in
    // the same pass.
    if (!measurement.temperature_valid ||
        measurement.temperature > MAX_TEMPERATURE) {
        fan.turn_on();
    } else if (measurement.temperature > 40.0 && !fan.isOn()) {
        fan.turn_on();
    } else if (measurement.temperature < 35.0 && fan.isOn()) {
        fan.turn_off();
    }

    ClickEncoder::Button encoder_btn = encoder.getButton();
    if (g_cb.controller.state == control::OperationState::Fault) {
        SetLoadOutput(0);
        if (encoder_btn == ClickEncoder::Clicked) {
            if (g_cb.controller.fault == control::FaultReason::AdcFailure) {
                g_cb.adc_initialized = InitializeAdc();
                if (g_cb.adc_initialized) {
                    control::acknowledgeFault(g_cb.controller, millis());
                }
            } else if (g_cb.controller.fault !=
                       control::FaultReason::DisplayFailure &&
                       measurement.adcValid() &&
                       measurement.temperature_valid) {
                const control::SafetyLimits recovery_limits = {
                    MAX_CURRENT * 1.1, 0.0, MAX_TEMPERATURE,
                    MAX_INPUT_VOLTAGE, MAX_WATTAGE
                };
                if (control::evaluateSafety(measurement, recovery_limits,
                                            g_cb.controller.state) ==
                    control::FaultReason::None) {
                    control::acknowledgeFault(g_cb.controller, now);
                }
            }
        }
        return;
    }

    if (g_cb.controller.state == control::OperationState::Completed) {
        SetLoadOutput(0);
        if (encoder_btn == ClickEncoder::Clicked) {
            control::acknowledgeCompleted(g_cb.controller, now);
        }
        return;
    }

    const control::SafetyLimits limits = {
        MAX_CURRENT * 1.1,
        voltage_set_point.as_double(),
        MAX_TEMPERATURE,
        MAX_INPUT_VOLTAGE,
        MAX_WATTAGE
    };
    const control::FaultReason unsafe_reason = control::evaluateSafety(
        measurement, limits, g_cb.controller.state);
    if (unsafe_reason != control::FaultReason::None) {
        LatchFault(unsafe_reason, now);
        return;
    }

    // After starting, require release before arming an immediate press-to-stop.
    // A false stop from switch bounce is safe; a delayed stop is not.
    const bool encoder_pressed = digitalRead(ENCODER_SW_PIN) == LOW;
    if (HandleImmediateStop()) {
        return;
    }

    // configuration setter control
    bool pos_changed = false;
    if (buttons[1].isRaisingEdge()) {
        setter_position = (setter_position - 1) % MAX_SET_POSITION;
        if (setter_position < 0) {
            setter_position += MAX_SET_POSITION;
        }
        pos_changed = true;
    } else if (buttons[2].isRaisingEdge()) {
        setter_position = (setter_position + 1) % MAX_SET_POSITION;
        pos_changed = true;
    }

    if (pos_changed) {
        UpdateCursorPosition();
    }
    // find which to set
    noInterrupts();
    auto encoder_value = encoder.getValue();
    interrupts();
    if (encoder_value != 0) {
        if (setter_position < 5) {
            current_set_point.change(encoder_value);
        } else {
            voltage_set_point.change(encoder_value);
        }
    }

    // display control
    if (buttons[3].isRaisingEdge()) {
        g_cb.page = (g_cb.page + 1) % MAX_PAGE;
    }
    if (buttons[0].isRaisingEdge()) {
        g_cb.page = (g_cb.page - 1) % MAX_PAGE;
        if (g_cb.page < 0) {
            g_cb.page += MAX_PAGE;
        }
    }

    // Track the physical press time directly. ClickEncoder's Held event has a
    // different duration and must not be confused with the 3 second start hold.
    const double cutoff_voltage = voltage_set_point.as_double() >
        MIN_SOURCE_VOLTAGE ? voltage_set_point.as_double() : MIN_SOURCE_VOLTAGE;
    if (g_cb.controller.state == control::OperationState::Idle) {
        if (encoder_pressed && !g_cb.start_press_active) {
            g_cb.start_press_active = true;
            g_cb.start_pressed_ms = now;
        } else if (!encoder_pressed) {
            g_cb.start_press_active = false;
        }

        if (g_cb.start_press_active &&
            control::hasElapsed(now, g_cb.start_pressed_ms,
                                control::kStartHoldMilliseconds)) {
            if (measurement.safety_voltage < MIN_SOURCE_VOLTAGE) {
                LatchFault(control::FaultReason::NoSource, now);
                return;
            }
            if (measurement.safety_voltage <= cutoff_voltage) {
                if (StartDischarge(g_cb.start_pressed_ms)) {
                    CompleteDischarge(millis());
                }
                return;
            }
            StartDischarge(g_cb.start_pressed_ms);
            return;
        }
    }

    if (g_cb.controller.state != control::OperationState::Running) {
        SetLoadOutput(0);
        return;
    }

    if (control::qualifyUndervoltage(g_cb.undervoltage,
                                     measurement.safety_voltage,
                                     measurement.safety_voltage_valid,
                                     cutoff_voltage,
                                     now)) {
        CompleteDischarge(now);
        return;
    }

    const uint32_t sample_elapsed = control::elapsedMilliseconds(
        now, g_cb.update_last);
    g_cb.mah += measurement.current * sample_elapsed / 3600.0;
    g_cb.watt_h += measurement.current * measurement.voltage *
        sample_elapsed / 3600000.0;
    g_cb.update_last = now;

    // The analog AD8629/shunt loop is the fast current servo. Firmware supplies
    // an absolute schematic-derived command, never an accumulated correction.
    double target_current = control::boundedCurrentTarget(
        current_set_point.as_double(),
        measurement.safety_voltage,
        measurement.temperature,
        CONTINUOUS_WATTAGE,
        THERMAL_DERATE_START,
        MAX_TEMPERATURE);
    if (measurement.safety_voltage < MIN_SOURCE_VOLTAGE) {
        target_current = 0.0;
    }
    const uint16_t target_code =
        control::theoreticalDacCodeForCurrent(target_current);
    const uint16_t output_code = control::slewDacCode(
        ad5541.getValue(), target_code, now, g_cb.output_last);
    g_cb.output_last = now;
    SetLoadOutput(output_code);
}


void setup()
{
    g_cb.controller = control::ControllerState();

    // Establish safe physical outputs before any UI delay or device probing.
    SPI.begin();
    ad5541.begin();
    SetLoadOutput(0);
    fan.init();
    fan.turn_on();

    // Bound every I2C transaction so a failed display cannot freeze control.
    Wire.begin();
    Wire.setWireTimeout(WIRE_TIMEOUT_US, true);
    Wire.clearWireTimeoutFlag();
    lcd.init();
    g_cb.display_available = !Wire.getWireTimeoutFlag();
    Wire.clearWireTimeoutFlag();
    if (g_cb.display_available) {
        lcd.home();
        lcd.print("@DC Active Load@");
        lcd.setCursor(0, 1);
        lcd.print("       20260817");
        lcd.home();
        if (Wire.getWireTimeoutFlag()) {
            g_cb.display_available = false;
            Wire.clearWireTimeoutFlag();
            LatchFault(control::FaultReason::DisplayFailure, millis());
        }
    }

    // load set point from eeprom
    if (EEPROM.read(EEPROM_VERSION_ADDR) != EEPROM_VERSION) {
        EEPROM.write(EEPROM_VERSION_ADDR, EEPROM_VERSION);
        SaveSetPointToEEPROM();
    } else {
        const bool current_valid =
            current_set_point.load_from_eeprom(EEPROM_CURRENT_ADDR);
        const bool voltage_valid =
            voltage_set_point.load_from_eeprom(EEPROM_VOLTAGE_ADDR);
        if (!current_valid || !voltage_valid) {
            SaveSetPointToEEPROM();
        }
    }

    delay(400);

    // Cursor position
    UpdateCursorPosition();

    // Timer
    Timer1.initialize(1000);
    Timer1.attachInterrupt(timer_one_isr);

    // Temperature averaging runs before the fan is allowed to turn off.
    lm35.init();

    // One bounded initialization attempt enters the normal fault model instead
    // of blocking setup forever. A click on FAULT ADC retries safely.
    g_cb.adc_initialized = InitializeAdc();
    if (!g_cb.adc_initialized) {
        LatchFault(control::FaultReason::AdcFailure, millis());
    }

    // Buttons
    buttons[0].init();
    buttons[1].init();
    buttons[2].init();
    buttons[3].init();

    if (g_cb.display_available) {
        lcd.clear();
        if (Wire.getWireTimeoutFlag()) {
            g_cb.display_available = false;
            Wire.clearWireTimeoutFlag();
            LatchFault(control::FaultReason::DisplayFailure, millis());
        }
    }
    g_cb.display_last = millis() - DISPLAY_UPDATE_INTERVAL_MS;
}


void loop()
{
    if (HandleImmediateStop()) {
        return;
    }
    if (UpdateSensors()) {
        ProcessControl();
    }

    const uint32_t now = millis();
    if (g_cb.display_available &&
        control::hasElapsed(now, g_cb.display_last,
                            DISPLAY_UPDATE_INTERVAL_MS)) {
        const bool display_ok = UpdateDisplay();
        g_cb.display_last = now;
        if (!display_ok || Wire.getWireTimeoutFlag()) {
            Wire.clearWireTimeoutFlag();
            g_cb.display_available = false;
            LatchFault(control::FaultReason::DisplayFailure, millis());
        }
    }
}

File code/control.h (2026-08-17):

#ifndef ELECTRONIC_DC_LOAD_CONTROL_H
#define ELECTRONIC_DC_LOAD_CONTROL_H

// The control model deliberately has no Arduino dependencies.  Hardware code
// can copy its readings into a MeasurementSnapshot and act on the resulting
// state without making the safety decisions themselves.

#include <stdint.h>

namespace control {

enum class OperationState : uint8_t {
    Idle = 0,
    Running,
    Fault,
    Calibration,
    Completed
};

enum class FaultReason : uint8_t {
    None = 0,
    AdcFailure,
    TemperatureSensorFailure,
    Overcurrent,
    Undervoltage,
    Overtemperature,
    Overvoltage,
    Overpower,
    NoSource,
    DisplayFailure
};

struct MeasurementSnapshot {
    double current;
    double voltage;
    double temperature;
    bool current_valid;
    bool voltage_valid;
    bool temperature_valid;
    uint32_t timestamp_ms;

    // These are deliberately separate from current/voltage.  The latter may
    // contain user calibration for display and control; safety_current and
    // safety_voltage must come from the nominal schematic transfer functions.
    double safety_current;
    double safety_voltage;
    bool safety_current_valid;
    bool safety_voltage_valid;

    bool adcValid() const
    {
        return safety_current_valid && safety_voltage_valid;
    }
};

struct SafetyLimits {
    double max_current;
    double min_voltage;
    double max_temperature;
    double max_voltage;
    double max_power;
};

// Checks are ordered deliberately: an ADC failure, then a temperature sensor
// failure, then electrical limits, then the thermal limit.  Invalid safety
// measurements are unsafe in every state.  Undervoltage is intentionally not
// a fault: a qualified low-voltage cutoff is a normal Completed state.
inline FaultReason evaluateSafety(const MeasurementSnapshot& measurement,
                                  const SafetyLimits& limits,
                                  OperationState state)
{
    if (!measurement.adcValid()) {
        return FaultReason::AdcFailure;
    }
    if (!measurement.temperature_valid) {
        return FaultReason::TemperatureSensorFailure;
    }
    if (measurement.safety_current > limits.max_current) {
        return FaultReason::Overcurrent;
    }
    if (measurement.safety_voltage > limits.max_voltage &&
        limits.max_voltage > 0.0) {
        return FaultReason::Overvoltage;
    }
    if (measurement.safety_current * measurement.safety_voltage >
            limits.max_power &&
        limits.max_power > 0.0) {
        return FaultReason::Overpower;
    }
    if (measurement.temperature > limits.max_temperature) {
        return FaultReason::Overtemperature;
    }
    (void)state;
    return FaultReason::None;
}

// Unsigned subtraction gives the intended result across a uint32_t millis()
// rollover, provided an interval is shorter than one full timer cycle.
inline uint32_t elapsedMilliseconds(uint32_t now_ms, uint32_t then_ms)
{
    return static_cast<uint32_t>(now_ms - then_ms);
}

inline bool hasElapsed(uint32_t now_ms,
                       uint32_t then_ms,
                       uint32_t interval_ms)
{
    return elapsedMilliseconds(now_ms, then_ms) >= interval_ms;
}

// Schematic-derived transfer functions.  These are nominal safety values and
// must not be replaced by calibration when checking absolute limits.
static const double kDacReferenceVolts = 5.0;
static const double kDacDividerTopOhms = 39000.0;
static const double kDacDividerBottomOhms = 10000.0;
static const double kCurrentShuntOhms = 0.005;
static const double kCurrentSenseGain = 50.0; // INA213
// The design files say 9.9 kOhm, but the purchase record for the assembled
// board says R5 is 9.09 kOhm. Fitted-part evidence takes precedence.
static const double kInputDividerRatio = 10.09; // 9.09 kOhm / 1 kOhm
static const double kMaximumTheoreticalCurrentAmps = 15.0;
static const uint16_t kTheoreticalDacHardCapCode = 4817U;

inline double theoreticalCurrentFromSenseVoltage(double sense_voltage)
{
    return sense_voltage / (kCurrentSenseGain * kCurrentShuntOhms);
}

inline double theoreticalVoltageFromDivider(double divider_voltage)
{
    return divider_voltage * kInputDividerRatio;
}

inline double theoreticalCurrentFromDacCode(uint16_t dac_code)
{
    const double dac_voltage =
        static_cast<double>(dac_code) * kDacReferenceVolts / 65536.0;
    const double shunt_voltage = dac_voltage *
        kDacDividerBottomOhms /
        (kDacDividerTopOhms + kDacDividerBottomOhms);
    return shunt_voltage / kCurrentShuntOhms;
}

inline uint16_t theoreticalDacCodeForCurrent(double current_amps)
{
    if (current_amps <= 0.0) {
        return 0U;
    }
    if (current_amps >= kMaximumTheoreticalCurrentAmps) {
        return kTheoreticalDacHardCapCode;
    }

    const double dac_voltage = current_amps * kCurrentShuntOhms *
        (kDacDividerTopOhms + kDacDividerBottomOhms) /
        kDacDividerBottomOhms;
    const double code = dac_voltage * 65536.0 / kDacReferenceVolts;
    // Round nominal values to the nearest DAC code, then enforce the
    // immutable 15 A ceiling independently of any calibration.
    const uint32_t rounded = static_cast<uint32_t>(code + 0.5);
    return rounded > kTheoreticalDacHardCapCode ?
        kTheoreticalDacHardCapCode : static_cast<uint16_t>(rounded);
}

// Conservative default: no more than 5 A/s in either direction.  The code
// rate is derived from the same schematic transfer function as the command.
static const double kDefaultSlewRateAmpsPerSecond = 5.0;
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

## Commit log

2017-09-06 Remove the old version of schematics
    [Electronic DC Load.sch, Electronic DC Load_v2.sch, Electronic DC Load_v3.sch]
2017-09-06 Update components
    [Electronic DC Load.sch]
2017-09-06 Remove the resistor from the input pin of AD8293
    [Electronic DC Load.sch]
2017-09-07 Add EC11 Rotary Encoder
    [Electronic DC Load.sch]
2017-09-09 First layouts
    [Electronic DC Load.brd, Electronic DC Load.sch]
2017-09-09 Fixed capacitors packages
    [Electronic DC Load.brd]
2017-09-09 Remove accidentally add cycle.
    [Electronic DC Load.brd]
2017-09-09 Make the ground connection of Rsense a litte stronger
    [Electronic DC Load.brd]
2017-09-09 Finalized V1 for Manufacturing
    [Electronic DC Load.brd]
2017-09-11 Fix the thermal decouple too small for PCB house
    [Electronic DC Load.brd]
2017-09-11 Update the LCD1602 hole size to 3mm
    Dont know why SPARKFUN made the choice to use only 2.8 MM drill hole....
    [Electronic DC Load.brd, Electronic DC Load.sch]
2017-09-11 Change debouncing filter network resistor to 1K
    [Electronic DC Load.brd, Electronic DC Load.sch]
2017-09-15 Fix lableling errors
    Fix a few errors in the labeling of resistors and capacitors
    [Electronic DC Load.brd, Electronic DC Load.sch]
2017-09-17 Remove the ground bridge for Rsense
    I made the ground bridge not sure if it's needed.
    And obviously, it doesn't. And removing it will tremendously increase the accuracy of INA213!!!
    [Electronic DC Load.brd, Electronic DC Load.sch]
2017-09-23 Refactored ADC code path
2017-09-23 Make the update function of ADC return value too
2017-09-24 Refactor Buttons
2017-09-24 Refactored FAN control
2017-09-25 PID prototype
2017-09-25 Refactored the buttons
2017-09-25 Limited the max current to 15000mA
2017-09-26 Add a max current limitation
2017-09-26 Oh no... it was not stable for anything less than 200ma
2017-09-27 Make the PID frame constant
2017-09-27 Re-implemented the PID controller
2017-09-27 Tune the real PID
2017-10-01 Add cut off voltage
2017-10-30 Fixed the encoder unresposive issue
    [main.cc]
2026-08-16 chore(build): restore reproducible AVR build
    Use the Ubuntu Arduino toolchain paths, document WSL setup, and express the 15 A template limit as a compile-time integer so the legacy firmware builds cleanly.
2026-08-16 fix(firmware): harden load safety controls
    Bound ADC waits, latch measurement and thermal faults, validate persisted setpoints, and prevent PID windup. Add host-side driver and controller tests so the safety behavior can be verified without hardware.
    [ad7190.h, ad7190_test.cc, adc.h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]
2026-08-17 fix(firmware): harden load control and protection
    Use fitted-component nominal values for immutable safety decisions, replace incremental DAC control with bounded positional output, and make ADC, display, startup, cutoff, and thermal failure paths deterministic. Add host coverage and document value provenance and remaining physical validation limits.
    [ad7190.h, ad7190_test.cc, adc.h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]

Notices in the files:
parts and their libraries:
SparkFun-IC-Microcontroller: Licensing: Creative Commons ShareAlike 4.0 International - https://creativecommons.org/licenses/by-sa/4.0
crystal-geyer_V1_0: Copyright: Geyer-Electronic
